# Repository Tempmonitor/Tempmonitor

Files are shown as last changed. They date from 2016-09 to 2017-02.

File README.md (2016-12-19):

#Temp monitor
Temp monitor is a device the monitors system resources. It connects to a computer with a micro usb cable and a host program written in C# collects and sends system information to the device. 

The device is equiped with four 3 character 8-segments led displays. The device is controlled by a ATiny45 running the V-USB library to create create a HID USB device. 

More information about hardware, firmware and host softwar can be found in the subfolders of the repository.

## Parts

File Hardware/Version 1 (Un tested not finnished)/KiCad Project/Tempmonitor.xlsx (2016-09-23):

Part/Designator | Seeed SKU | MFR | Quantity
U8,U1,U3,U6 | 304080005 | SYD3642ASR | 4
C1 | 302020005 | TAJC476K006RNJ | 1
U5 | 310010018 | ATMEGA16U2-MU | 1
U2,U4,U7,U9 | 310040027 | TM1637 | 4
C3,C4 | 302010001 | CC0402JRNPO9BN100 | 2
Y1 | 306010054 | X053201602002 | 1
C2 | 302010139 | CC0603KRX7R8BB105 | 1
R10,R4,R3,R2,R1,R8,R7,R6,R5 | 301010361 | RC0805FR-0710KL | 9
R9,R11 | 301010052 | RC0402FR-0722RL | 2
F1 | 307010040 | MF-MSMF050-2 | 1
USB1 | 320010000 | ST-USB-001G | 1

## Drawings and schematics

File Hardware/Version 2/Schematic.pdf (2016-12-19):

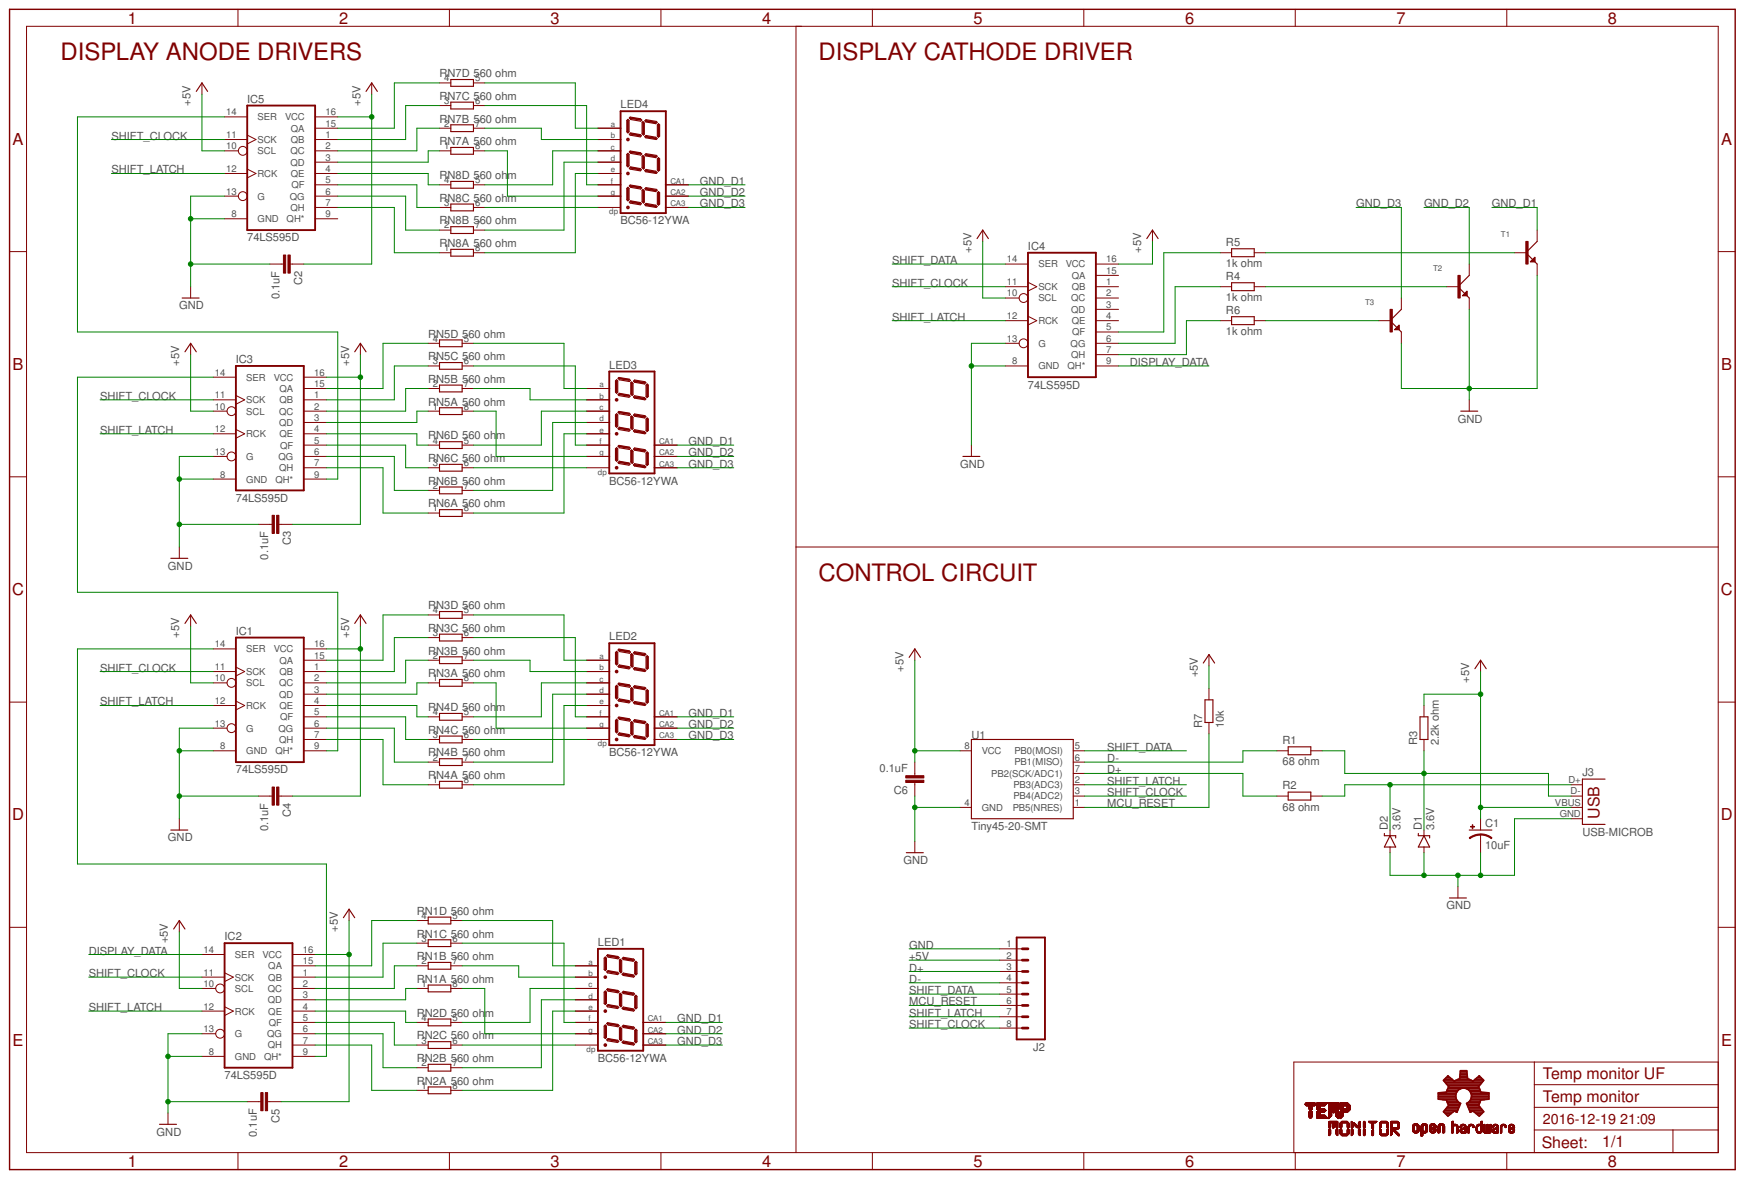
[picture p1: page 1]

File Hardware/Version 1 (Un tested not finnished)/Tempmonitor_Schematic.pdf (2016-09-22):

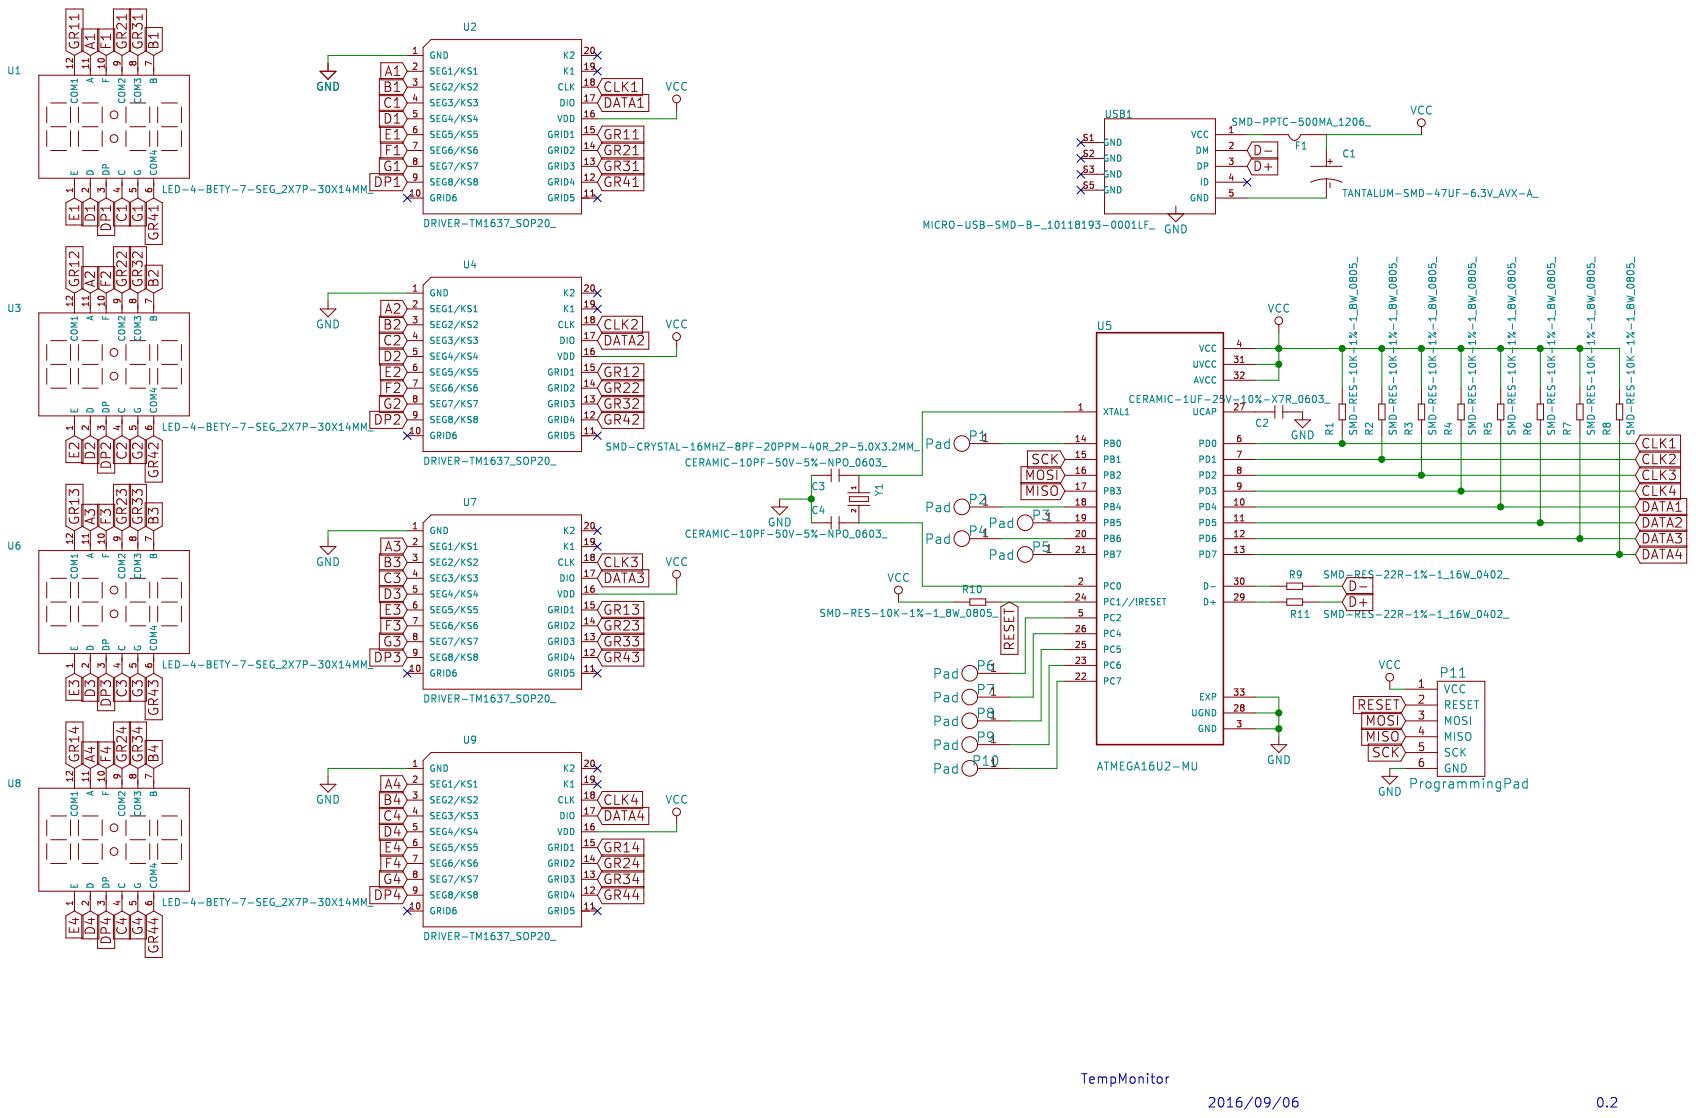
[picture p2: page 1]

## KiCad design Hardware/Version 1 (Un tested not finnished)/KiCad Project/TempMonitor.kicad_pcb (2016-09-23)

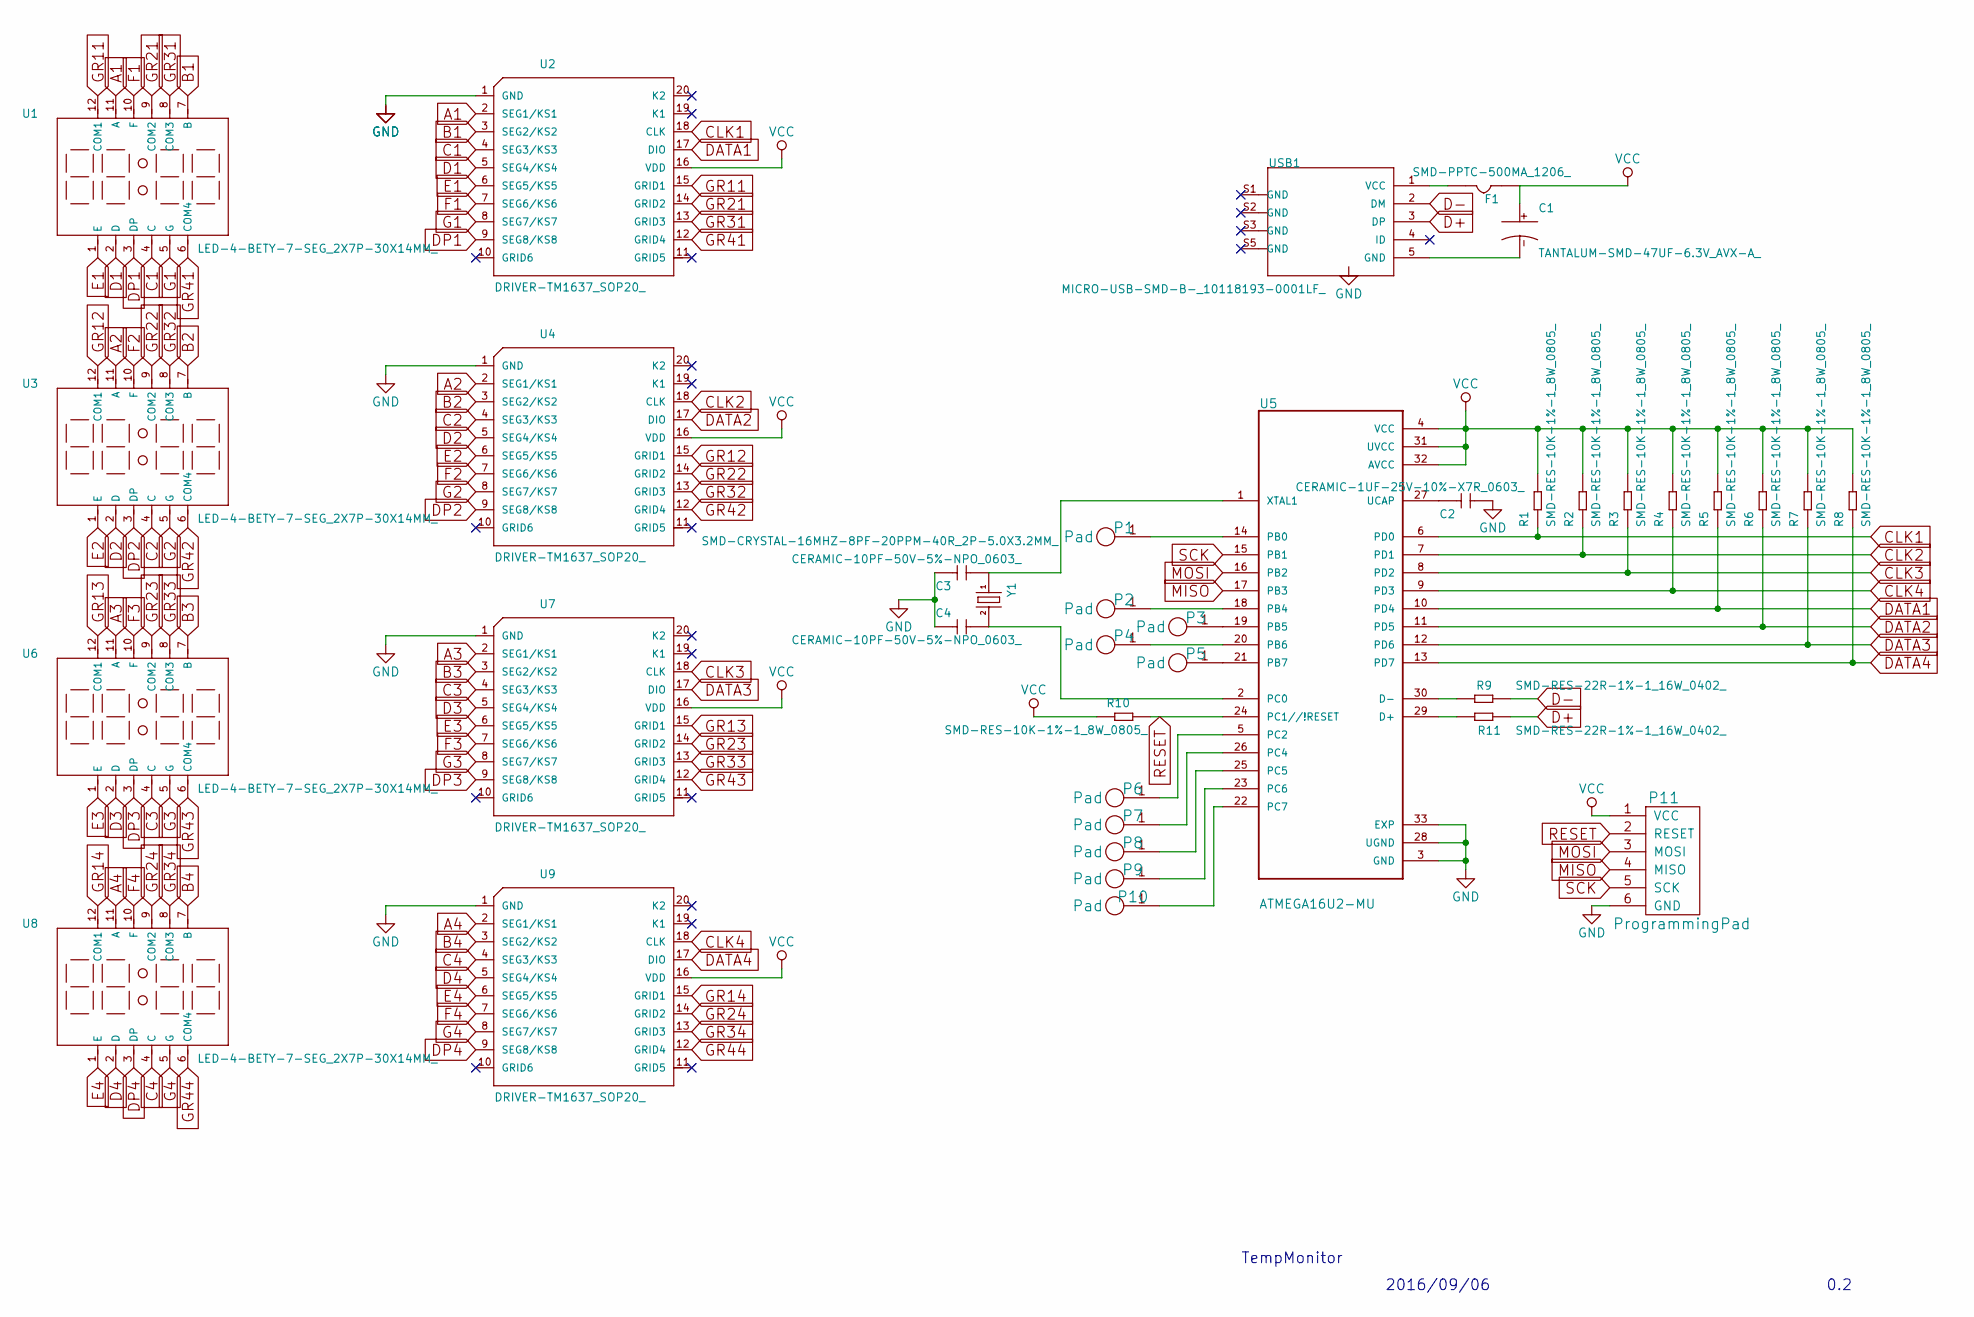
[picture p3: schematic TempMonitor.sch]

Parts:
C1: TANTALUM-SMD-47UF-6.3V_AVX-A_; AVX-A
C2: CERAMIC-1UF-25V-10%-X7R_0603_; C0603
C3, C4: CERAMIC-10PF-50V-5%-NPO_0603_; C0603
F1: SMD-PPTC-500MA_1206_; F1206
P1, P2, P3, P4, P5, P6, P7, P8, P9, P10: Pad
P11: ProgrammingPad
R1, R2, R3, R4, R5, R6, R7, R8, R10: SMD-RES-10K-1%-1_8W_0805_; R0805
R9, R11: SMD-RES-22R-1%-1_16W_0402_; R0402
U1, U3, U6, U8: LED-4-BETY-7-SEG_2X7P-30X14MM_; LCD12-2.54-30.0X14.0X7.3MM
U2, U4, U7, U9: DRIVER-TM1637_SOP20_; SOP20-1.27-12.7X7.65MM
U5: ATMEGA16U2-MU; QFN50P500X500X100-33N
USB1: MICRO-USB-SMD-B-_10118193-0001LF_; MICRO-USB5+6P-SMD-0.65-B
Y1: SMD-CRYSTAL-16MHZ-8PF-20PPM-40R_2P-5.0X3.2MM_; X2-SMD-5.0X3.2X1.3MM

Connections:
A1: U1.11 (A), U2.2 (SEG1/KS1)
A2: U3.11 (A), U4.2 (SEG1/KS1)
A3: U6.11 (A), U7.2 (SEG1/KS1)
A4: U8.11 (A), U9.2 (SEG1/KS1)
B1: U1.7 (B), U2.3 (SEG2/KS2)
B2: U3.7 (B), U4.3 (SEG2/KS2)
B3: U6.7 (B), U7.3 (SEG2/KS2)
B4: U8.7 (B), U9.3 (SEG2/KS2)
C1: U1.4 (C), U2.4 (SEG3/KS3)
C2: U3.4 (C), U4.4 (SEG3/KS3)
C3: U6.4 (C), U7.4 (SEG3/KS3)
C4: U8.4 (C), U9.4 (SEG3/KS3)
CLK1: R1.1, U2.18 (CLK), U5.6 (PD0)
CLK2: R2.1, U4.18 (CLK), U5.7 (PD1)
CLK3: R3.1, U5.8 (PD2), U7.18 (CLK)
CLK4: R4.1, U5.9 (PD3), U9.18 (CLK)
D1: U1.2 (D), U2.5 (SEG4/KS4)
D2: U3.2 (D), U4.5 (SEG4/KS4)
D3: U6.2 (D), U7.5 (SEG4/KS4)
D4: U8.2 (D), U9.5 (SEG4/KS4)
D+: R11.1, USB1.3 (DP)
D-: R9.1, USB1.2 (DM)
DATA1: R5.1, U2.17 (DIO), U5.10 (PD4)
DATA2: R6.1, U4.17 (DIO), U5.11 (PD5)
DATA3: R7.1, U5.12 (PD6), U7.17 (DIO)
DATA4: R8.1, U5.13 (PD7), U9.17 (DIO)
DP1: U1.3 (DP), U2.9 (SEG8/KS8)
DP2: U3.3 (DP), U4.9 (SEG8/KS8)
DP3: U6.3 (DP), U7.9 (SEG8/KS8)
DP4: U8.3 (DP), U9.9 (SEG8/KS8)
E1: U1.1 (E), U2.6 (SEG5/KS5)
E2: U3.1 (E), U4.6 (SEG5/KS5)
E3: U6.1 (E), U7.6 (SEG5/KS5)
E4: U8.1 (E), U9.6 (SEG5/KS5)
F1: U1.10 (F), U2.7 (SEG6/KS6)
F2: U3.10 (F), U4.7 (SEG6/KS6)
F3: U6.10 (F), U7.7 (SEG6/KS6)
F4: U8.10 (F), U9.7 (SEG6/KS6)
G1: U1.5 (G), U2.8 (SEG7/KS7)
G2: U3.5 (G), U4.8 (SEG7/KS7)
G3: U6.5 (G), U7.8 (SEG7/KS7)
G4: U8.5 (G), U9.8 (SEG7/KS7)
GND: C2.2, C3.1, C4.1, P11.6 (GND), U2.1 (GND), U4.1 (GND), U5.3 (GND), U5.28 (UGND), U5.33 (EXP), U7.1 (GND), U9.1 (GND)
GR11: U1.12 (COM1), U2.15 (GRID1)
GR12: U3.12 (COM1), U4.15 (GRID1)
GR13: U6.12 (COM1), U7.15 (GRID1)
GR14: U8.12 (COM1), U9.15 (GRID1)
GR21: U1.9 (COM2), U2.14 (GRID2)
GR22: U3.9 (COM2), U4.14 (GRID2)
GR23: U6.9 (COM2), U7.14 (GRID2)
GR24: U8.9 (COM2), U9.14 (GRID2)
GR31: U1.8 (COM3), U2.13 (GRID3)
GR32: U3.8 (COM3), U4.13 (GRID3)
GR33: U6.8 (COM3), U7.13 (GRID3)
GR34: U8.8 (COM3), U9.13 (GRID3)
GR41: U1.6 (COM4), U2.12 (GRID4)
GR42: U3.6 (COM4), U4.12 (GRID4)
GR43: U6.6 (COM4), U7.12 (GRID4)
GR44: U8.6 (COM4), U9.12 (GRID4)
MISO: P11.4 (MISO), U5.17 (PB3)
MOSI: P11.3 (MOSI), U5.16 (PB2)
unnamed: C1.-, USB1.5 (GND)
unnamed: C2.1, U5.27 (UCAP)
unnamed: C3.2, U5.1 (XTAL1), Y1.1
unnamed: C4.2, U5.2 (PC0), Y1.2
unnamed: F1.1, USB1.1 (VCC)
unnamed: P1.1, U5.14 (PB0)
unnamed: P2.1, U5.18 (PB4)
unnamed: P3.1, U5.19 (PB5)
unnamed: P4.1, U5.20 (PB6)
unnamed: P5.1, U5.21 (PB7)
unnamed: P6.1, U5.5 (PC2)
unnamed: P7.1, U5.26 (PC4)
unnamed: P8.1, U5.25 (PC5)
unnamed: P9.1, U5.23 (PC6)
unnamed: P10.1, U5.22 (PC7)
unnamed: R9.2, U5.30 (D-)
unnamed: R11.2, U5.29 (D+)
unnamed: USB1.S3 (GND), USB1.S4 (GND)
unnamed: USB1.S5 (GND), USB1.S6 (GND)
RESET: P11.2 (RESET), R10.2, U5.24 (PC1//!RESET)
SCK: P11.5 (SCK), U5.15 (PB1)
VCC: C1.+, F1.2, P11.1 (VCC), R1.2, R2.2, R3.2, R4.2, R5.2, R6.2, R7.2, R8.2, R10.1, U2.16 (VDD), U4.16 (VDD), U5.4 (VCC), U5.31 (UVCC), U5.32 (AVCC), U7.16 (VDD), U9.16 (VDD)

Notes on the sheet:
TempMonitor
2016/09/06
0.2

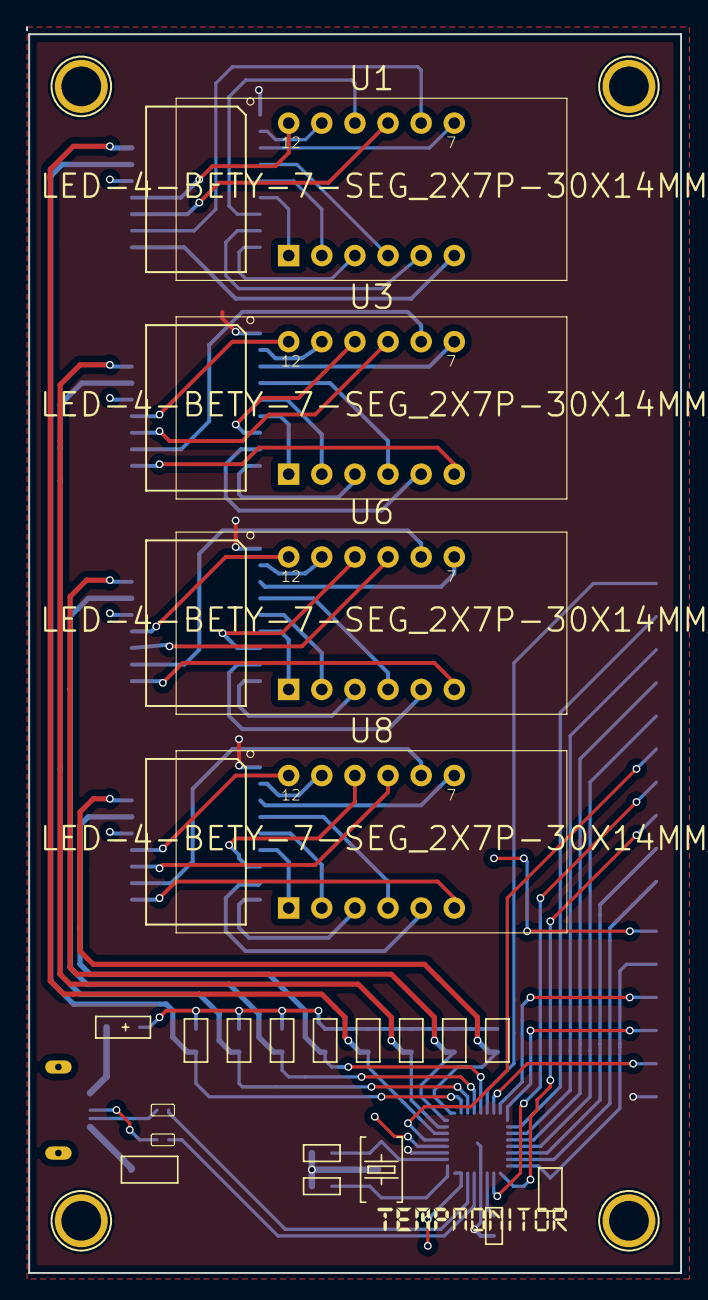
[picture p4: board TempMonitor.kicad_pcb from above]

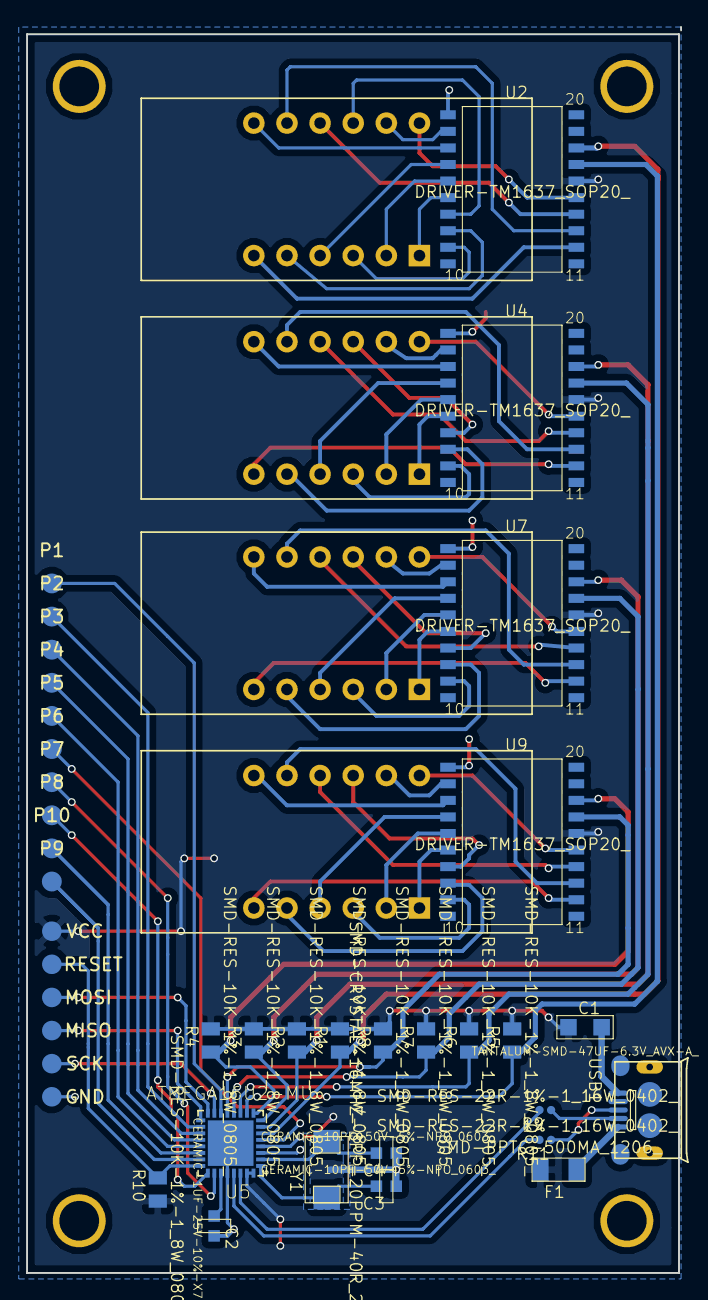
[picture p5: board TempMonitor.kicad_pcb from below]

Board: 2 copper layers, 50.2 x 95.6 mm, 38 parts (33 on the bottom side), 83 nets.

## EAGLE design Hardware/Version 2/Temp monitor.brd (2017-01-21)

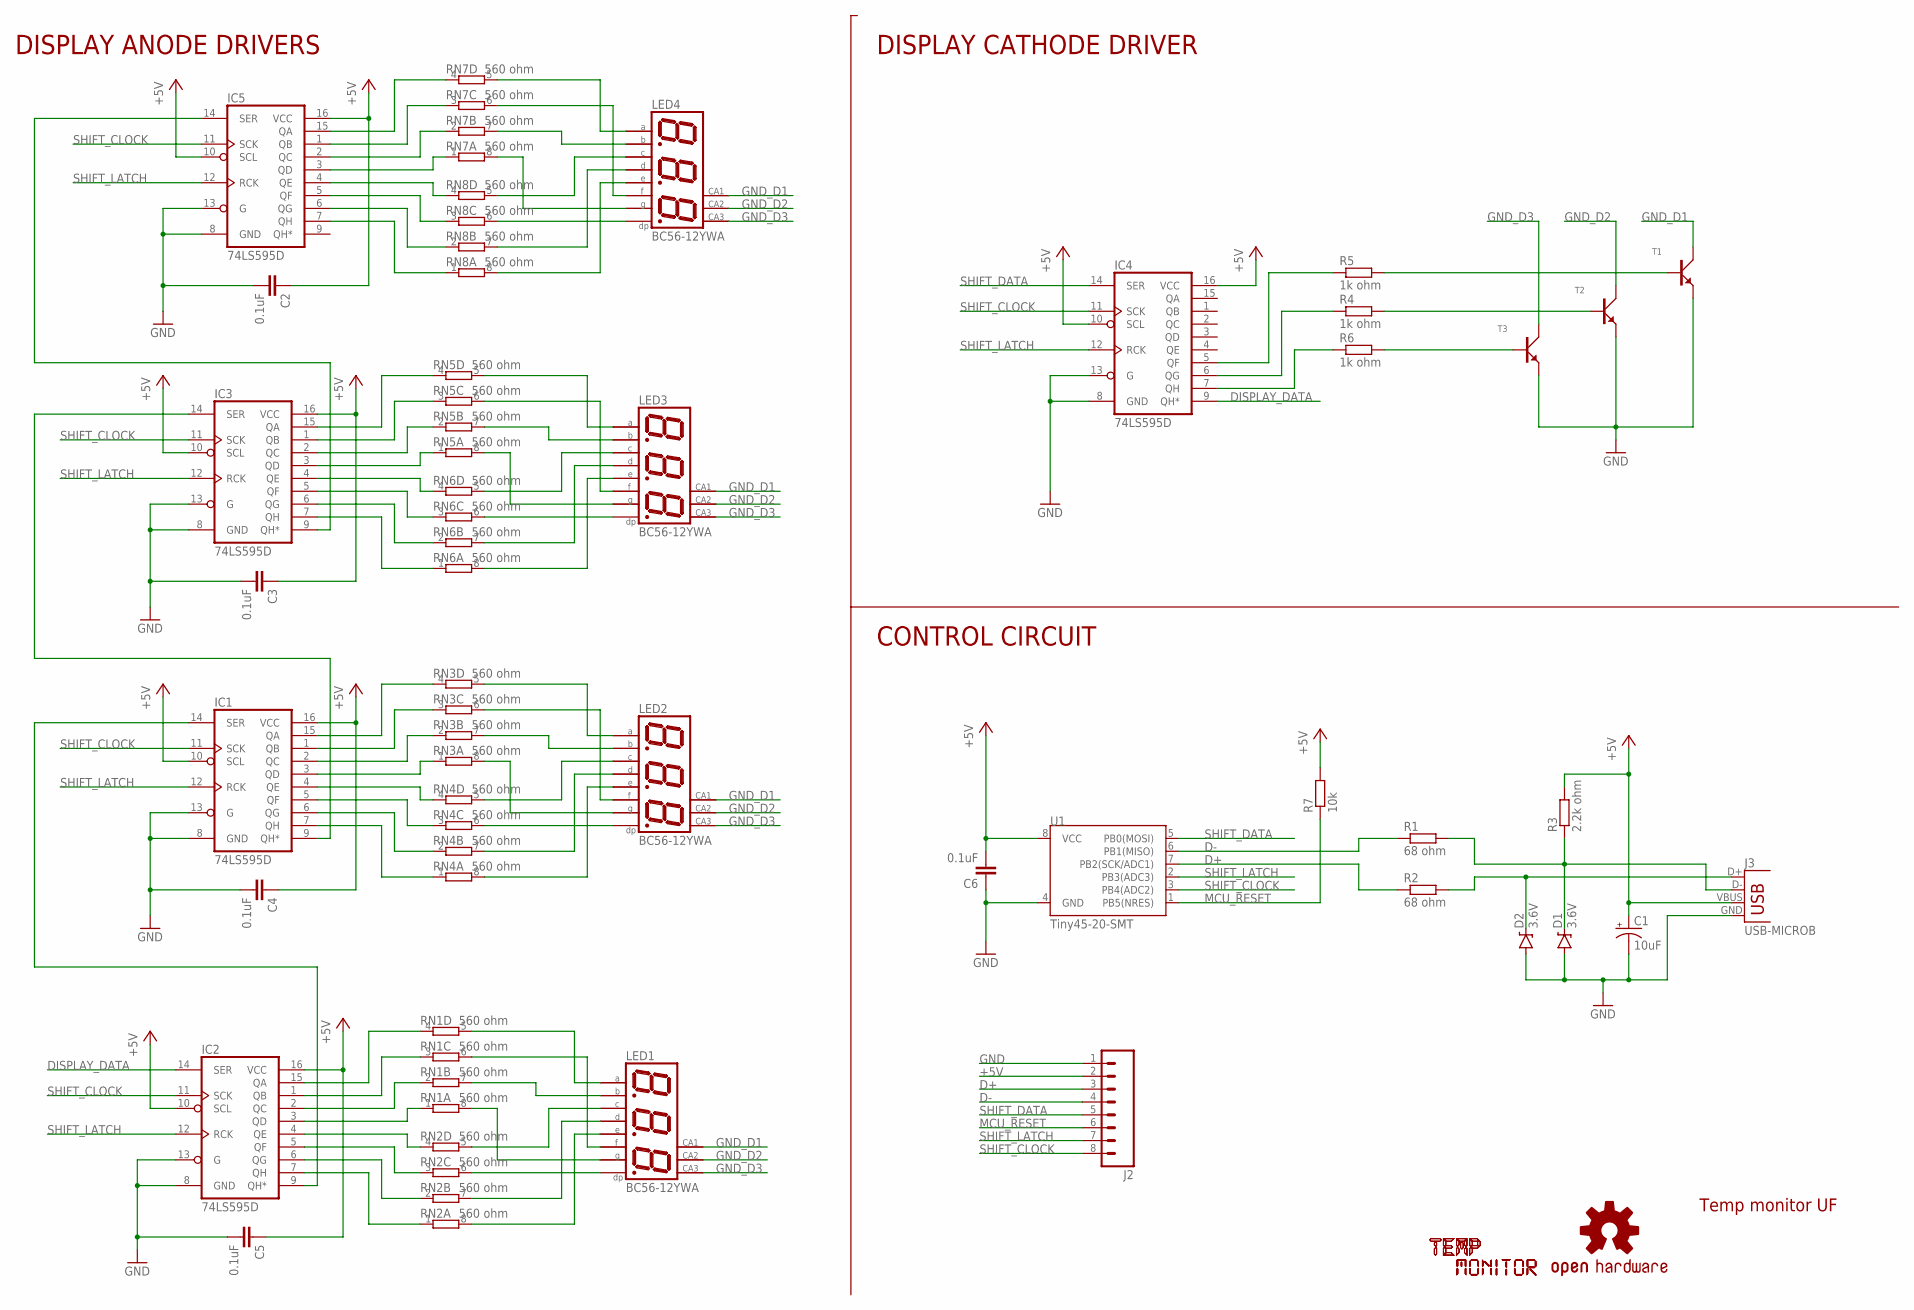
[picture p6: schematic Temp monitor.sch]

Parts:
C1: 10uF; NIPPON_F80
C2, C3, C4, C5, C6: 0.1uF; C0805
D1, D2: 3.6V; SOD-123
IC1, IC2, IC3, IC4, IC5: 74LS595D; SO16
J2: TP_8
J3: USB-MICROB
LED1, LED2, LED3, LED4: BC56-12YWA; BX56-12
LOGO1: OSHW-LOGOL; OSHW-LOGO-L
R1, R2: 68 ohm; R0805W
R3: 2.2k ohm; R0805W
R4, R5, R6: 1k ohm; R0805W
R7: 10k; R0805W
RN1, RN2, RN3, RN4, RN5, RN6, RN7, RN8: 560 ohm; EXBV8V
T1, T2, T3: NPN; SOT23
U1: Tiny45-20-SMT; SO08-EIAJ
U$1, U$2: LOGO; LOGO_M

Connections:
+5V: C1.+, C2.1, C3.1, C4.1, C5.1, C6.2, IC1.10 (SCL), IC1.16 (VCC), IC2.10 (SCL), IC2.16 (VCC), IC3.10 (SCL), IC3.16 (VCC), IC4.10 (SCL), IC4.16 (VCC), IC5.10 (SCL), IC5.16 (VCC), J2.2, J3.VBUS, R3.2, R7.2, U1.8 (VCC)
D+: J2.3, R2.1, U1.7 (PB2(SCK/ADC1))
D-: J2.4, R1.1, U1.6 (PB1(MISO))
DISPLAY_DATA: IC2.14 (SER), IC4.9 (QH*)
GND: C1.-, C2.2, C3.2, C4.2, C5.2, C6.1, D1.A, D2.A, IC1.8 (GND), IC1.13 (G), IC2.8 (GND), IC2.13 (G), IC3.8 (GND), IC3.13 (G), IC4.8 (GND), IC4.13 (G), IC5.8 (GND), IC5.13 (G), J2.1, J3.GND, T1.2 (E), T2.2 (E), T3.2 (E), U1.4 (GND)
GND_D1: LED1.12 (CA), LED2.12 (CA), LED3.12 (CA), LED4.12 (CA), T1.3 (C)
GND_D2: LED1.9 (CA), LED2.9 (CA), LED3.9 (CA), LED4.9 (CA), T2.3 (C)
GND_D3: LED1.8 (CA), LED2.8 (CA), LED3.8 (CA), LED4.8 (CA), T3.3 (C)
MCU_RESET: J2.6, R7.1, U1.1 (PB5(NRES))
unnamed: D1.C, J3.D-, R1.2, R3.1
unnamed: D2.C, J3.D+, R2.2
unnamed: IC2.15 (QA), RN1.4 (1)
unnamed: IC2.1 (QB), RN1.3 (1)
unnamed: IC4.7 (QH), R6.1
unnamed: IC2.2 (QC), RN1.2 (1)
unnamed: IC2.3 (QD), RN1.1
unnamed: IC2.4 (QE), RN2.4 (1)
unnamed: IC2.5 (QF), RN2.3 (1)
unnamed: IC2.6 (QG), RN2.2 (1)
unnamed: IC2.7 (QH), RN2.1
unnamed: LED1.4 (C), RN2.5 (2)
unnamed: LED1.7 (B), RN1.7 (2)
unnamed: LED1.11 (A), RN1.5 (2)
unnamed: LED1.10 (F), RN1.6 (2)
unnamed: LED1.5 (G), RN1.8 (2)
unnamed: LED1.2 (D), RN2.7 (2)
unnamed: LED1.3 (DP), RN2.6 (2)
unnamed: LED1.1 (E), RN2.8 (2)
unnamed: IC1.15 (QA), RN3.4 (1)
unnamed: IC1.1 (QB), RN3.3 (1)
unnamed: IC1.2 (QC), RN3.2 (1)
unnamed: IC1.3 (QD), RN3.1
unnamed: IC1.4 (QE), RN4.4 (1)
unnamed: IC1.5 (QF), RN4.3 (1)
unnamed: IC1.6 (QG), RN4.2 (1)
unnamed: IC1.7 (QH), RN4.1
unnamed: LED2.1 (E), RN4.8 (2)
unnamed: LED2.2 (D), RN4.7 (2)
unnamed: LED2.4 (C), RN4.5 (2)
unnamed: IC4.6 (QG), R4.1
unnamed: IC4.5 (QF), R5.1
unnamed: IC5.15 (QA), RN7.4 (1)
unnamed: R4.2, T2.1 (B)
unnamed: R5.2, T1.1 (B)
unnamed: R6.2, T3.1 (B)
unnamed: LED2.7 (B), RN3.7 (2)
unnamed: LED2.11 (A), RN3.5 (2)
unnamed: LED2.10 (F), RN3.6 (2)
unnamed: LED2.5 (G), RN3.8 (2)
unnamed: LED2.3 (DP), RN4.6 (2)
unnamed: IC3.15 (QA), RN5.4 (1)
unnamed: IC3.1 (QB), RN5.3 (1)
unnamed: IC3.2 (QC), RN5.2 (1)
unnamed: IC3.3 (QD), RN5.1
unnamed: IC3.4 (QE), RN6.4 (1)
unnamed: IC3.5 (QF), RN6.3 (1)
unnamed: IC3.6 (QG), RN6.2 (1)
unnamed: IC3.7 (QH), RN6.1
unnamed: LED3.1 (E), RN6.8 (2)
unnamed: LED3.2 (D), RN6.7 (2)
unnamed: LED3.4 (C), RN6.5 (2)
unnamed: LED3.7 (B), RN5.7 (2)
unnamed: LED3.11 (A), RN5.5 (2)
unnamed: LED3.10 (F), RN5.6 (2)
unnamed: LED3.5 (G), RN5.8 (2)
unnamed: LED3.3 (DP), RN6.6 (2)
unnamed: IC5.1 (QB), RN7.3 (1)
unnamed: IC5.2 (QC), RN7.2 (1)
unnamed: IC5.3 (QD), RN7.1
unnamed: IC5.4 (QE), RN8.4 (1)
unnamed: IC5.5 (QF), RN8.3 (1)
unnamed: IC5.6 (QG), RN8.2 (1)
unnamed: IC5.7 (QH), RN8.1
unnamed: LED4.1 (E), RN8.8 (2)
unnamed: LED4.2 (D), RN8.7 (2)
unnamed: LED4.4 (C), RN8.5 (2)
unnamed: LED4.7 (B), RN7.7 (2)
unnamed: LED4.11 (A), RN7.5 (2)
unnamed: LED4.10 (F), RN7.6 (2)
unnamed: LED4.5 (G), RN7.8 (2)
unnamed: LED4.3 (DP), RN8.6 (2)
unnamed: IC3.9 (QH*), IC5.14 (SER)
unnamed: IC1.9 (QH*), IC3.14 (SER)
unnamed: IC1.14 (SER), IC2.9 (QH*)
SHIFT_CLOCK: IC1.11 (SCK), IC2.11 (SCK), IC3.11 (SCK), IC4.11 (SCK), IC5.11 (SCK), J2.8, U1.3 (PB4(ADC2))
SHIFT_DATA: IC4.14 (SER), J2.5, U1.5 (PB0(MOSI))
SHIFT_LATCH: IC1.12 (RCK), IC2.12 (RCK), IC3.12 (RCK), IC4.12 (RCK), IC5.12 (RCK), J2.7, U1.2 (PB3(ADC3))

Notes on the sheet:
DISPLAY CATHODE DRIVER
DISPLAY ANODE DRIVERS
Temp monitor UF
CONTROL CIRCUIT

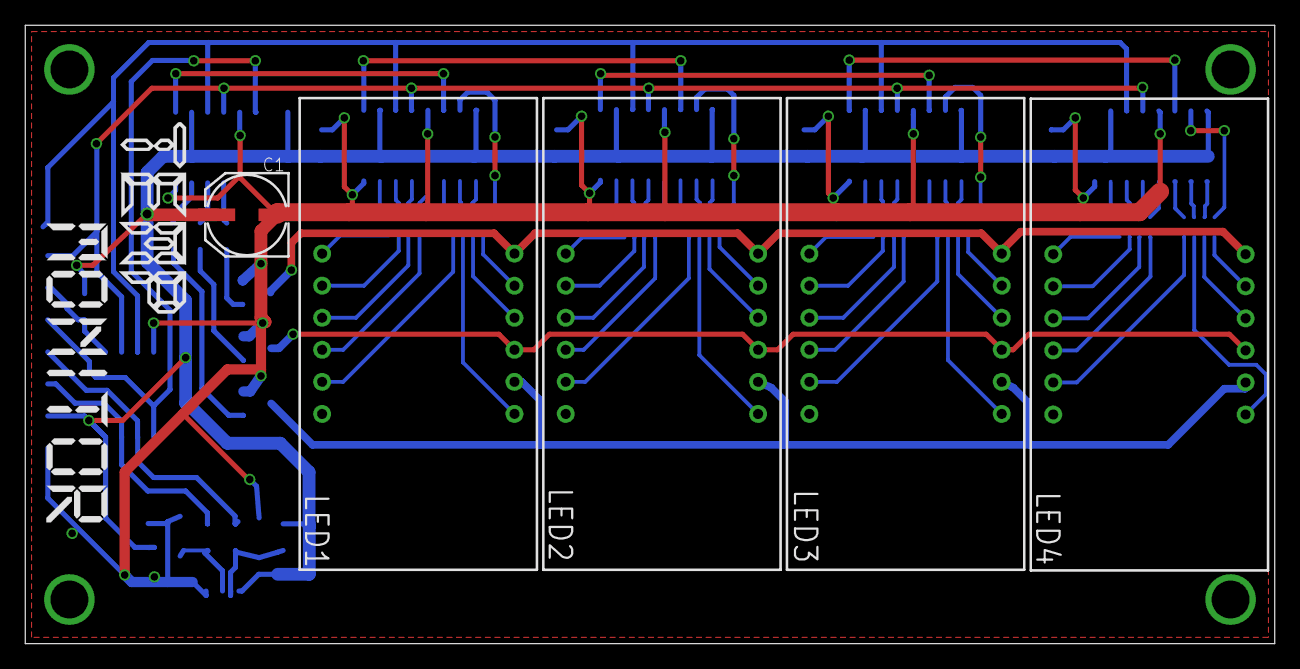
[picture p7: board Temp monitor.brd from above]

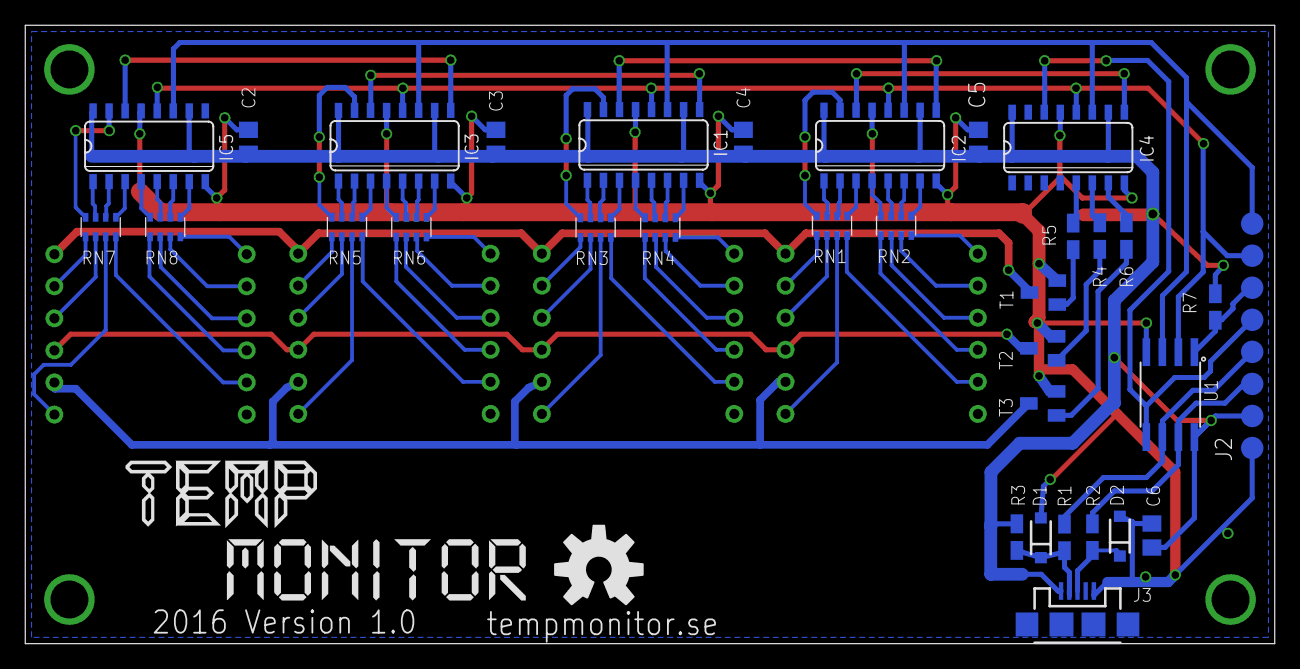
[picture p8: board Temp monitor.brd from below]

Board: 2 copper layers, 99.0 x 49.0 mm, 41 parts (35 on the bottom side), 87 nets.

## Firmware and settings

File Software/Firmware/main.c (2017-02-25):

/*--------------------------------------------------------------------------
Copyright (C) 2016  Temp monitor UF

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
You should have received a copy of the GNU General Public License along
with this program; if not, write to the Free Software Foundation, Inc.,
51 Franklin Street, Fifth Floor, Boston, MA 02110-1301 USA.

The base usb framework for this software is based of the V-USB example
project hid-data written by Christian Starkjohann and licensed with GNU GPL v2.
--------------------------------------------------------------------------*/

#include "main.h"


/* USB interface */

#define HIDSERIAL_INBUFFER_SIZE 32

PROGMEM const char usbHidReportDescriptor[USB_CFG_HID_REPORT_DESCRIPTOR_LENGTH] = {    /* USB report descriptor */
    0x06, 0x00, 0xff,              // USAGE_PAGE (Generic Desktop)
    0x09, 0x01,                    // USAGE (Vendor Usage 1)
    0xa1, 0x01,                    // COLLECTION (Application)
    0x15, 0x00,                    //   LOGICAL_MINIMUM (0)
    0x26, 0xff, 0x00,              //   LOGICAL_MAXIMUM (255)
    0x75, 0x08,                    //   REPORT_SIZE (8)
    0x95, 0x08,                    //   REPORT_COUNT (8)
    0x09, 0x00,                    //   USAGE (Undefined)
    0x82, 0x02, 0x01,              //   INPUT (Data,Var,Abs,Buf)
    0x95, HIDSERIAL_INBUFFER_SIZE, //   REPORT_COUNT (32)
    0x09, 0x00,                    //   USAGE (Undefined)
    0xb2, 0x02, 0x01,              //   FEATURE (Data,Var,Abs,Buf)
    0xc0                           // END_COLLECTION
};

static uchar received = 0;
static uchar inBuffer[HIDSERIAL_INBUFFER_SIZE];
static uchar reportId = 0;
static uchar bytesRemaining;
static uchar* pos;

static uchar    bytesRemaining;

/* Called when host requests data */
uchar   usbFunctionRead(uchar *data, uchar len)
{
    return 0;
}

/* Called when host sends data */
uchar   usbFunctionWrite(uchar *data, uchar len)
{
    if (reportId == 0) {
        int i;
        if(len > bytesRemaining)
            len = bytesRemaining;
        bytesRemaining -= len;
        for(i=0;i<len;i++) {
            if (data[i]!=0) {
                *pos++ = data[i];
             }
        }
        if (bytesRemaining == 0) {
            received = 1;
            *pos++ = 0;
            return 1;
        } else {
            return 0;
        }
    } else {
        return 1;
    }
}

usbMsgLen_t usbFunctionSetup(uchar data[8])
{
    usbRequest_t    *rq = (usbRequest_t *)data;
    reportId = rq->wValue.bytes[0];
    if((rq->bmRequestType & USBRQ_TYPE_MASK) == USBRQ_TYPE_CLASS){    /* HID class request */
        if(rq->bRequest == USBRQ_HID_GET_REPORT){
          /* wValue: ReportType (highbyte), ReportID (lowbyte) */
            /* since we have only one report type, we can ignore the report-ID */
            return USB_NO_MSG;  /* use usbFunctionRead() to obtain data */
        }else if(rq->bRequest == USBRQ_HID_SET_REPORT){
            /* since we have only one report type, we can ignore the report-ID */
            pos = inBuffer;
            bytesRemaining = rq->wLength.word;
            if(bytesRemaining > sizeof(inBuffer))
                bytesRemaining = sizeof(inBuffer);
            return USB_NO_MSG;  /* use usbFunctionWrite() to receive data from host */
        }
    }else{
        /* ignore vendor type requests, we don't use any */
    }
    return 0;
}

void USBDisconnect()
{
    uchar   i;
    usbDeviceDisconnect();  /* enforce re-enumeration, do this while interrupts are disabled! */
    i = 0;
    while(--i){             /* fake USB disconnect for > 250 ms */
        wdt_reset();
        _delay_ms(1);
    }
}

#define abs(x) ((x) > 0 ? (x) : (-x))

// Called by V-USB after device reset
void hadUsbReset() {
    int frameLength, targetLength = (unsigned)(1499 * (double)F_CPU / 10.5e6 + 0.5);
    int bestDeviation = 9999;
    uchar trialCal, bestCal, step, region;

    // do a binary search in regions 0-127 and 128-255 to get optimum OSCCAL
    for(region = 0; region <= 1; region++) {
        frameLength = 0;
        trialCal = (region == 0) ? 0 : 128;

        for(step = 64; step > 0; step >>= 1) {
            if(frameLength < targetLength) // true for initial iteration
                trialCal += step; // frequency too low
            else
                trialCal -= step; // frequency too high

            OSCCAL = trialCal;
            frameLength = usbMeasureFrameLength();

            if(abs(frameLength-targetLength) < bestDeviation) {
                bestCal = trialCal; // new optimum found
                bestDeviation = abs(frameLength -targetLength);
            }
        }
    }

    OSCCAL = bestCal;
}



int main(void)
{
    //wdt_enable(WDTO_1S);
    wdt_disable();

    //Init IO
	SHIFT_DDR |= 1 << CLOCK_PIN | 1 << DATA_PIN | 1 << LATCH_PIN;

    usbInit();

    USBDisconnect();

    usbDeviceConnect();
    sei();

    DisplayInit();

    DisplayWrite(0,123);
    DisplayWrite(1,456);
    DisplayWrite(2,789);
    DisplayWrite(3,012);
    DisplayBrightness(250);

	received = 0;

	int connectionTimeout = 30000;

    for(;;){
        wdt_reset();

        if(received != 0)
        {
			//Reset the connection timeout counting
			connectionTimeout = 30000;

			//Convert 255 into zeros (Computer can't send zeros)
			for(uchar x = 0; x != 8; x++)
			{
				if(inBuffer[x] == 255)
					inBuffer[x] = 0;
			}

			DisplayBrightness(inBuffer[1]);
            DisplayWrite(0, inBuffer[2]);
            DisplayWrite(1, inBuffer[3]);
            DisplayWrite(2, inBuffer[4]);
            DisplayWrite(3, inBuffer[5]);

            received = 0;
        }

        //Turn of display on connection timeout
        if(connectionTimeout == 0)
        {
            DisplayBrightness(0);
        }
        else
        {
            connectionTimeout--;
        }
        _delay_us(50);
        usbPoll();
    }
    return 0;
}

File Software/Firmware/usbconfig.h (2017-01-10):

/* Name: usbconfig.h
 * Project: V-USB, virtual USB port for Atmel's(r) AVR(r) microcontrollers
 * Author: Christian Starkjohann
 * Creation Date: 2005-04-01
 * Tabsize: 4
 * Copyright: (c) 2005 by OBJECTIVE DEVELOPMENT Software GmbH
 * License: GNU GPL v2 (see License.txt), GNU GPL v3 or proprietary (CommercialLicense.txt)
 */

 /*
    Modified by Temp monitor UF for Temp monitor project.
    Last modification:
*/



#ifndef __usbconfig_h_included__
#define __usbconfig_h_included__

/*
General Description:
This file is an example configuration (with inline documentation) for the USB
driver. It configures V-USB for USB D+ connected to Port D bit 2 (which is
also hardware interrupt 0 on many devices) and USB D- to Port D bit 4. You may
wire the lines to any other port, as long as D+ is also wired to INT0 (or any
other hardware interrupt, as long as it is the highest level interrupt, see
section at the end of this file).
*/

/* ---------------------------- Hardware Config ---------------------------- */

#define USB_CFG_IOPORTNAME      B
/* This is the port where the USB bus is connected. When you configure it to
 * "B", the registers PORTB, PINB and DDRB will be used.
 */
#define USB_CFG_DMINUS_BIT      1
/* This is the bit number in USB_CFG_IOPORT where the USB D- line is connected.
 * This may be any bit in the port.
 */
#define USB_CFG_DPLUS_BIT       2
/* This is the bit number in USB_CFG_IOPORT where the USB D+ line is connected.
 * This may be any bit in the port. Please note that D+ must also be connected
 * to interrupt pin INT0! [You can also use other interrupts, see section
 * "Optional MCU Description" below, or you can connect D- to the interrupt, as
 * it is required if you use the USB_COUNT_SOF feature. If you use D- for the
 * interrupt, the USB interrupt will also be triggered at Start-Of-Frame
 * markers every millisecond.]
 */
#define USB_CFG_CLOCK_KHZ       (F_CPU/1000)
/* Clock rate of the AVR in kHz. Legal values are 12000, 12800, 15000, 16000,
 * 16500, 18000 and 20000. The 12.8 MHz and 16.5 MHz versions of the code
 * require no crystal, they tolerate +/- 1% deviation from the nominal
 * frequency. All other rates require a precision of 2000 ppm and thus a
 * crystal!
 * Since F_CPU should be defined to your actual clock rate anyway, you should
 * not need to modify this setting.
 */
#define USB_CFG_CHECK_CRC       0
/* Define this to 1 if you want that the driver checks integrity of incoming
 * data packets (CRC checks). CRC checks cost quite a bit of code size and are
 * currently only available for 18 MHz crystal clock. You must choose
 * USB_CFG_CLOCK_KHZ = 18000 if you enable this option.
 */

/* ----------------------- Optional Hardware Config ------------------------ */

/* #define USB_CFG_PULLUP_IOPORTNAME   D */
/* If you connect the 1.5k pullup resistor from D- to a port pin instead of
 * V+, you can connect and disconnect the device from firmware by calling
 * the macros usbDeviceConnect() and usbDeviceDisconnect() (see usbdrv.h).
 * This constant defines the port on which the pullup resistor is connected.
 */
/* #define USB_CFG_PULLUP_BIT          4 */
/* This constant defines the bit number in USB_CFG_PULLUP_IOPORT (defined
 * above) where the 1.5k pullup resistor is connected. See description
 * above for details.
 */

/* --------------------------- Functional Range ---------------------------- */
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

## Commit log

2016-09-06 Initial hardware
    PCBnew not complete.
    [TempMonitor (Konfliktkopia för Erik Almbratt 2016-08-26).kicad_pcb, TempMonitor.kicad_pcb, TempMonitor.sch]
2016-09-22 Update
    Gerber files added, BOM added, PCB redone, separate clock traces for
    led-drivers made.
    [TempMonitor (Konfliktkopia för Erik Almbratt 2016-08-26).kicad_pcb, TempMonitor.kicad_pcb, TempMonitor.sch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]
2016-09-23 Update
    Logo exchanged, gerbers updated and BOM updated and redone, now with MPN
    instead of Seeed SKU.
    [TempMonitor.kicad_pcb, Tempmonitor.csv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]
2016-09-23 Hotfix
    Values not included in gerber.
    [TempMonitor.kicad_pcb, Tempmonitor.xlsx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]
2016-10-05 Added inital new pcb version
    [TempMonitor.kicad_pcb, TempMonitor.sch, Tempmonitor.csv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]
2016-10-06 Firmware base framework
2016-10-19 PCB layout
    PCB routed, need of silkscreen fixes. Directory clean up.
    [tempmonitor.brd, tempmonitor.sch, untitled.brd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]
2016-10-20 Added loggos
    [tempmonitor.brd, tempmonitor.sch]
2016-10-23 USB circuit fix
    USB circuit fix R3 incorrectly connected. Added filtering capacitors to MCU and shift registers. Centered displays.
    [tempmonitor.brd, tempmonitor.sch]
2016-10-23 Fix LED display wiring
    [tempmonitor.brd]
2016-10-25 PCB fix
    Removed C6 value+ more space for R3, R1 & D1
    [tempmonitor.brd]
2016-10-27 Hotfix
    Unnecessary front silkscreen removed, some silkscreen moved from front
    to back and silkscreen references moved.
    [TempMonitor.kicad_pcb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]
2016-11-23 Version 1.0
    [tempmonitor.brd, tempmonitor.sch]
2016-11-23 Gerber files Version 1.0
    [tempmonitor.GBL, tempmonitor.GBO, tempmonitor.GBS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]
2016-11-23 Fix corrupted file
    [tempmonitor.brd]
2016-12-19 Added schematic in PDF
    [Temp monitor.brd, Temp monitor.sch]
2016-12-22 Revert "Hotfix"
    This reverts commit b01ab2ca72f5422068492f297ba1483d4015dfa4.
    [TempMonitor.kicad_pcb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]
2016-12-23 Various updates Automatic oscillator calibration, display driver
    [main.c, main.h, usbconfig.h]
2017-01-07 Comments added and timer routine cleanup
2017-01-09 Device connection made and label change added
2017-01-10 USB Config update Updated VID, PID, vendor name and device name
2017-01-11 Return GPU load and temperature fix
2017-01-12 Changed VID & PID, added battery info
2017-01-14 Changed assemblyname and removed notfication ballones
2017-01-21 Fixed typo
    [Temp monitor.brd]
2017-02-02 Brightness control Using Timer1 compare match to control brightness of displays.

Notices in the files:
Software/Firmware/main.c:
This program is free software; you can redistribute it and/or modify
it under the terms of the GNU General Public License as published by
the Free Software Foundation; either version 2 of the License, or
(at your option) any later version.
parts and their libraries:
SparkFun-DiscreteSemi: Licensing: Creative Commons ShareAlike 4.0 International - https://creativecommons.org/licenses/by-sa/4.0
